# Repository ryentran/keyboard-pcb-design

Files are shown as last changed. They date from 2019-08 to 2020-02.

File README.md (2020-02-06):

# Keyboard PCB Design
This is a keyboard design for a 3x3 macropad created using KiCAD, Hasu's keyboard_parts [component library](https://github.com/tmk/kicad_lib_tmk) and [footprint library](https://github.com/tmk/keyboard_parts.pretty), and /u/techieee's [switch footprint library](https://github.com/egladman/keebs.pretty).

# Schematic
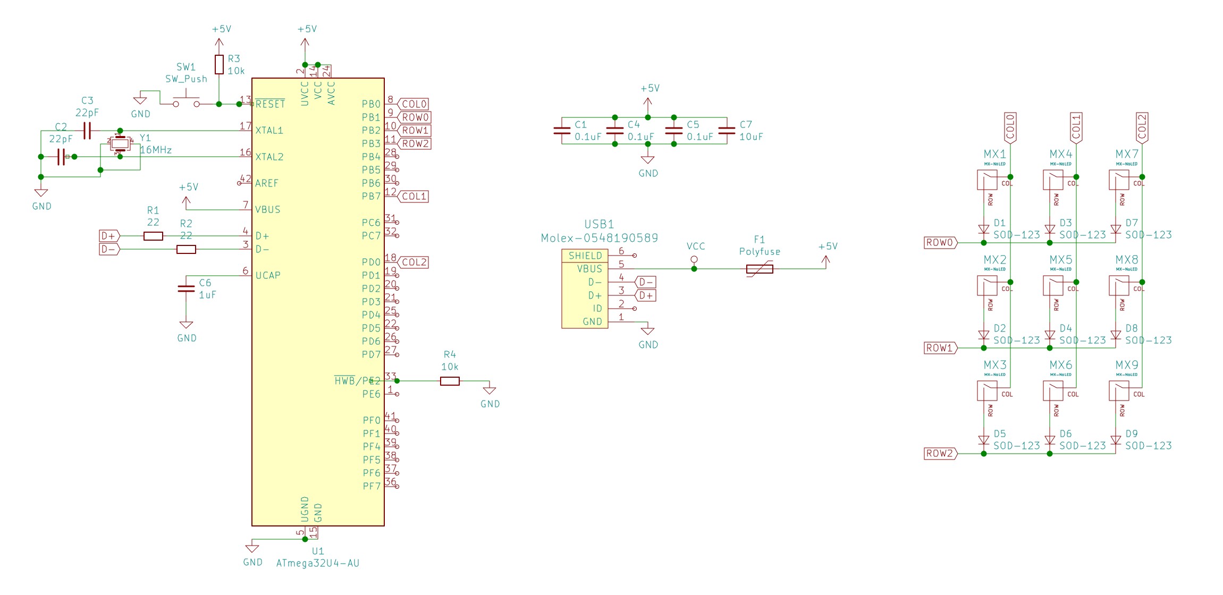
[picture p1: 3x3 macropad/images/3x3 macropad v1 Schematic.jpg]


# PCB
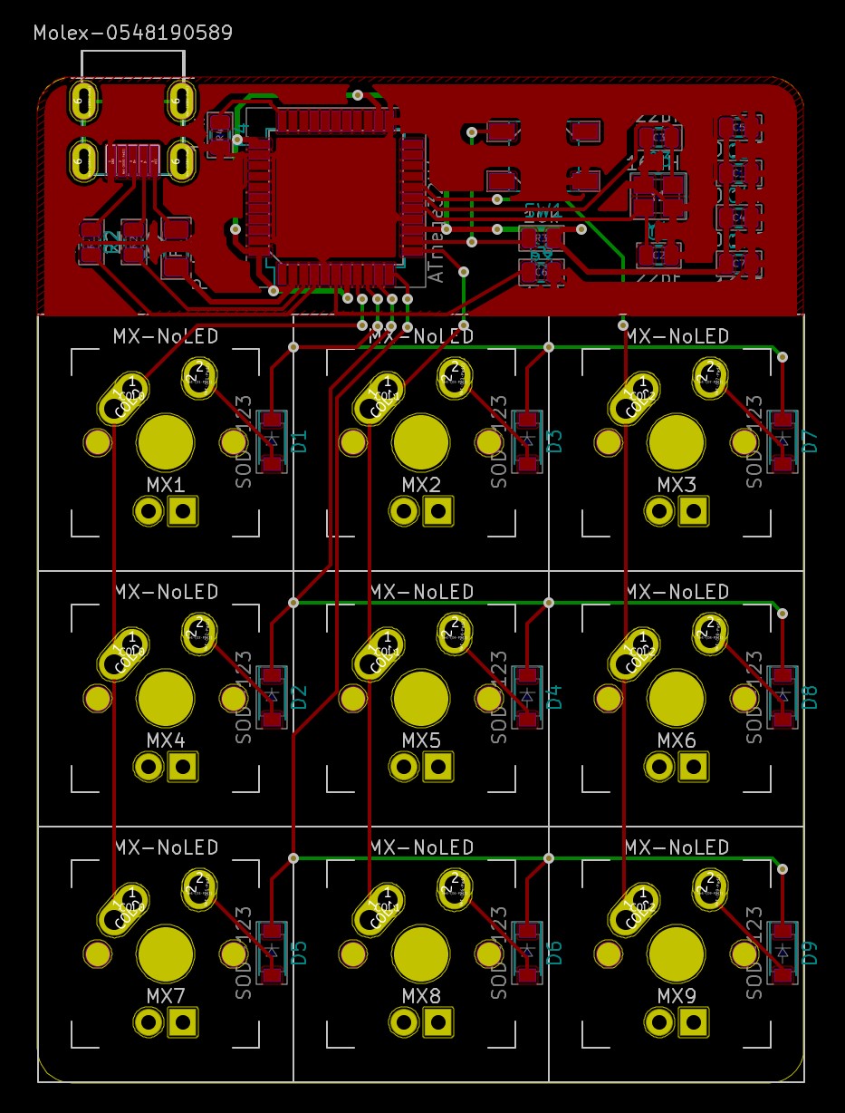
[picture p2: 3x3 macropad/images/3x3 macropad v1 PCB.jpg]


# Soldered PCB
After creating the schematic and pcb design for the macropad, the pcb was printed using prototyping services ([JLCPCB](https://jlcpcb.com/)). Once the pcb was received, SMD components were handsoldered to the board and tested for functionaility.
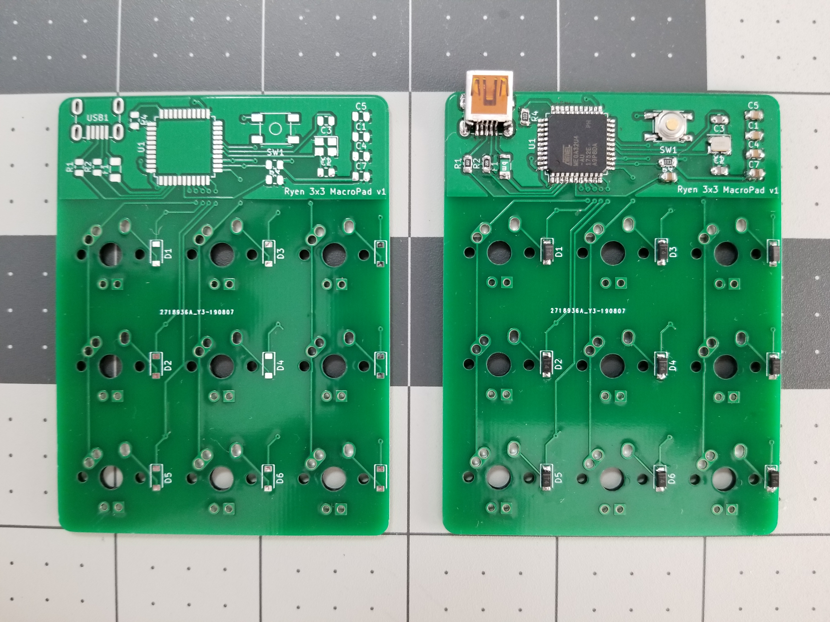
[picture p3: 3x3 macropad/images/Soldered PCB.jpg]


# Programming
The MCU used for this project is an atmega32u4 which was programmed with [QMK_firmware](https://github.com/qmk/qmk_firmware). To achieve this, the used MCU pins and key layout was defined in C header files. Once everything was setup, the hexfile was generated using a makefile and loaded onto the MCU using [QMK_toolbox](https://github.com/qmk/qmk_toolbox). To test the board, the pins across each key was shorted with a wire and the programmed key was executed.

# Mechanical Key Switches
The switches use for this macropad are Zealios 62g lubed with Krytox 205 Grade 0
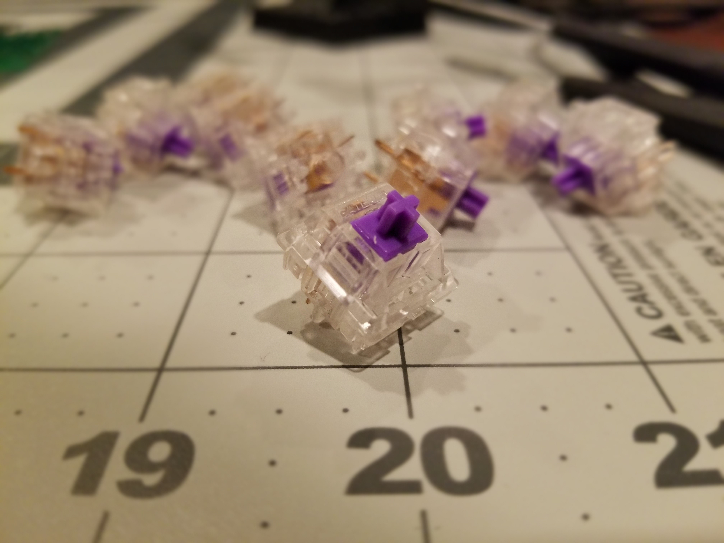
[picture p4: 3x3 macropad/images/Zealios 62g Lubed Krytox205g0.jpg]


# Finished Product
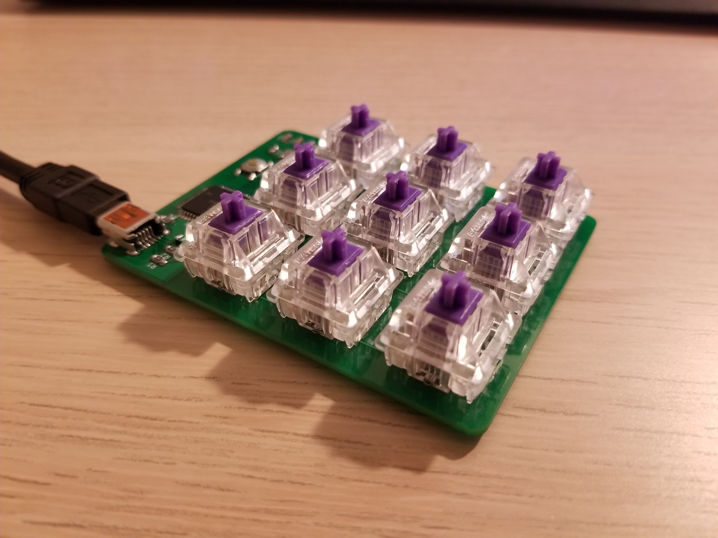
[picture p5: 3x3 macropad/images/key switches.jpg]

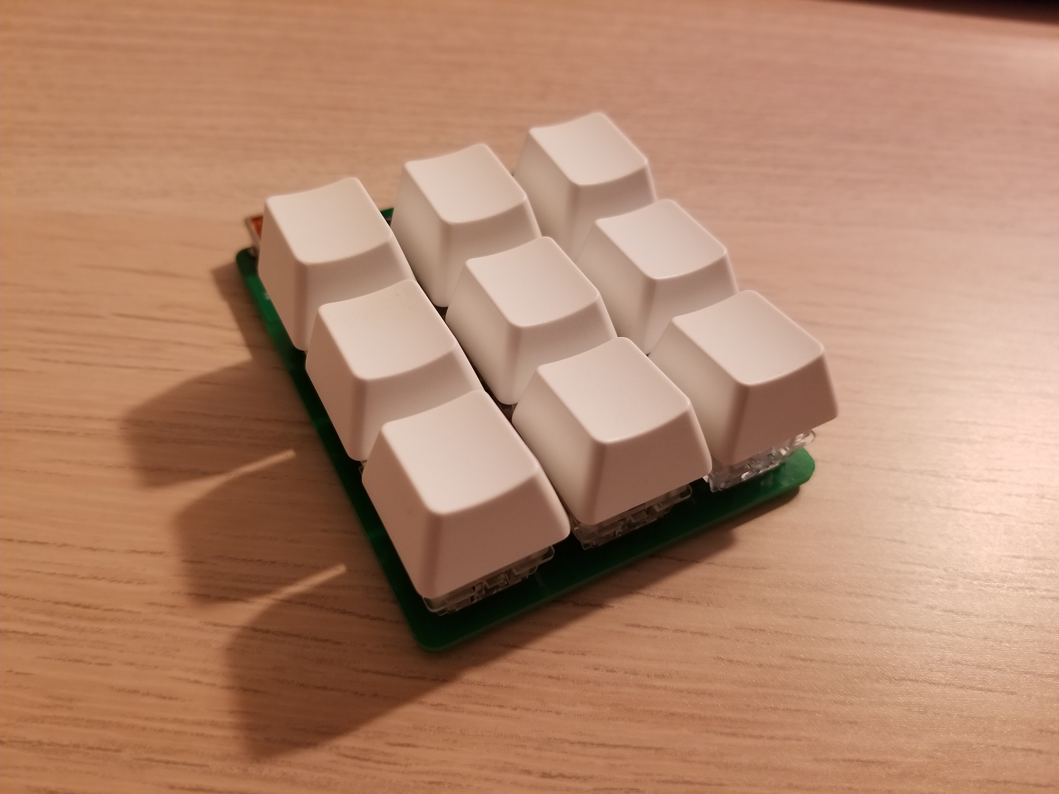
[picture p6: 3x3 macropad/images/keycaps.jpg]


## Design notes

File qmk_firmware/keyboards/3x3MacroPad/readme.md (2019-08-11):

# 3x3MacroPad

3x3MacroPad

A short description of the keyboard/project

Keyboard Maintainer: [Ryan](https://github.com/yourusername)  
Hardware Supported: The PCBs, controllers supported  
Hardware Availability: links to where you can find this hardware

Make example for this keyboard (after setting up your build environment):

    make 3x3MacroPad:default

See the [build environment setup](https://docs.qmk.fm/#/getting_started_build_tools) and the [make instructions](https://docs.qmk.fm/#/getting_started_make_guide) for more information. Brand new to QMK? Start with our [Complete Newbs Guide](https://docs.qmk.fm/#/newbs).

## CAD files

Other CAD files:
Alice/alice_plate_rev_C.DWG
Alice/alice_case_acrylic.DWG
Alice/alice_PCB_layout.DWG

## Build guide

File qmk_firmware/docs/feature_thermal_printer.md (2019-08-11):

# Thermal Printer

<!-- FIXME: Describe thermal printers support here. -->

## Thermal Printer Keycodes

|Key |Description |
|---|---|
|`PRINT_ON` |Start printing everything the user types|
|`PRINT_OFF`|Stop printing everything the user types |

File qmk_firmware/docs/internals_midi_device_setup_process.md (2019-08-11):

# group `midi_device_setup_process` {#group__midi__device__setup__process}

These are method that you must use to initialize and run a device.

## Summary

 Members                        | Descriptions                                
--------------------------------|---------------------------------------------
`public void `[`midi_device_init`](#group__midi__device__setup__process_1gaf29deddc94ea98a59daa0bde1aefd9d9)`(`[`MidiDevice`](#struct__midi__device)` * device)`            | Initialize a device.
`public void `[`midi_device_process`](#group__midi__device__setup__process_1gaa3d5993d0e998a1b59bbf5ab9c7b492b)`(`[`MidiDevice`](#struct__midi__device)` * device)`            | Process input data.

## Members

#### `public void `[`midi_device_init`](#group__midi__device__setup__process_1gaf29deddc94ea98a59daa0bde1aefd9d9)`(`[`MidiDevice`](#struct__midi__device)` * device)` {#group__midi__device__setup__process_1gaf29deddc94ea98a59daa0bde1aefd9d9}

Initialize a device.

You must call this before using the device in question.

#### Parameters
* `device` the device to initialize

#### `public void `[`midi_device_process`](#group__midi__device__setup__process_1gaa3d5993d0e998a1b59bbf5ab9c7b492b)`(`[`MidiDevice`](#struct__midi__device)` * device)` {#group__midi__device__setup__process_1gaa3d5993d0e998a1b59bbf5ab9c7b492b}

Process input data.

This method drives the input processing, you must call this method frequently if you expect to have your input callbacks called.

#### Parameters
* `device` the device to process

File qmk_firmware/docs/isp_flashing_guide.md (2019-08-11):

# ISP Flashing Guide

If you're having trouble flashing/erasing your board, and running into cryptic error messages like any of the following:

    libusb: warning [darwin_transfer_status] transfer error: timed out
    dfu.c:844: -ETIMEDOUT: Transfer timed out, NAK 0xffffffc4 (-60)
    atmel.c:1627: atmel_flash: flash data dfu_download failed.
    atmel.c:1629: Expected message length of 1072, got -60.
    atmel.c:1434: Error flashing the block: err -2.
    ERROR
    Memory write error, use debug for more info.
    commands.c:360: Error writing memory data. (err -4)

    dfu.c:844: -EPIPE: a) Babble detect or b) Endpoint stalled 0xffffffe0 (-32)
    Device is write protected.
    dfu.c:252: dfu_clear_status( 0x7fff4fc2ea80 )
    atmel.c:1434: Error flashing the block: err -2.
    ERROR
    Memory write error, use debug for more info.
    commands.c:360: Error writing memory data. (err -4)

You're likely going to need to ISP flash your board/device to get it working again. Luckily, this process is pretty straight-forward, provided you have any extra programmable keyboard, Pro Micro, or Teensy 2.0/Teensy 2.0++. There are also dedicated ISP flashers available for this, but most cost >$15, and it's assumed that if you are googling this error, this is the first you've heard about ISP flashing, and don't have one readily available (whereas you might have some other AVR board). __We'll be using a Teensy 2.0 or Pro Micro with Windows 10 in this guide__ - if you are comfortable doing this on another system, please consider editing this guide and contributing those instructions!   

## Software Needed

* [Teensy Loader](https://www.pjrc.com/teensy/loader.html) (if using a Teensy)
* QMK Toolbox (flash as usual - be sure to select the correct MCU) or `avrdude` via [WinAVR](http://www.ladyada.net/learn/avr/setup-win.html) (for Teensy & Pro Micro)

## Wiring

This is pretty straight-forward - we'll be connecting like-things to like-things in the following manner:

### Teensy 2.0

    Teensy B0  <-> Keyboard RESET
    Teensy B1  <-> Keyboard B1 (SCLK)
    Teensy B2  <-> Keyboard B2 (MOSI)
    Teensy B3  <-> Keyboard B3 (MISO)
    Teensy VCC <-> Keyboard VCC
    Teensy GND <-> Keyboard GND
    
### Pro Micro

    Pro Micro 10 (B6)  <-> Keyboard RESET
    Pro Micro 15 (B1)  <-> Keyboard B1 (SCLK)
    Pro Micro 16 (B2)  <-> Keyboard B2 (MOSI)
    Pro Micro 14 (B3)  <-> Keyboard B3 (MISO)
    Pro Micro VCC      <-> Keyboard VCC
    Pro Micro GND      <-> Keyboard GND

## The ISP Firmware (now pre-compiled)

The only difference between the .hex files below is which pin is connected to RESET. You can use them on other boards as well, as long as you're aware of the pins being used. If for some reason neither of these pins are available, [create an issue](https://github.com/qmk/qmk_firmware/issues/new), and we can generate one for you!

* Teensy 2.0: [`util/teensy_2.0_ISP_B0.hex`](https://github.com/qmk/qmk_firmware/blob/master/util/teensy_2.0_ISP_B0.hex) (`B0`)
* Pro Micro: [`util/pro_micro_ISP_B6_10.hex`](https://github.com/qmk/qmk_firmware/blob/master/util/pro_micro_ISP_B6_10.hex) (`B6/10`)

**Flash your Teenys/Pro Micro with one of these and continue - you won't need the file after flashing your ISP device.**

## Just the Bootloader File

If you just want to get things back to normal, you can flash only a bootloader from [`util/` folder](https://github.com/qmk/qmk_firmware/tree/master/util), and use your normal process to flash the firmware afterwards. Be sure to flash the correct bootloader for your chip:

* [`atmega32u4`](https://github.com/qmk/qmk_firmware/blob/master/util/bootloader_atmega32u4_1_0_0.hex) - Most keyboards, Planck Rev 1-5, Preonic Rev 1-2
* [`at90usb1286`](https://github.com/qmk/qmk_firmware/blob/master/util/bootloader_at90usb128x_1_0_1.hex) - Planck Light Rev 1
* [`atmega32a`](https://github.com/qmk/qmk_firmware/blob/master/util/bootloader_atmega32a_1_0_0.hex) - jj40

If you're not sure what your board uses, look in the `rules.mk` file for the keyboard in QMK. The `MCU =` line will have the value you need. It may differ between different versions of the board.

### Advanced/Production Techniques

If you'd like to flash both the bootloader **and** the regular firmware at the same time, you need to combine the files. 

1. Open the original firmware .hex file in a text editor
2. Remove the last line (which should be `:00000001FF` - this is an EOF message)
3. Copy the entire bootloader's contents onto a new line (with no empty lines between) and paste it at the end of the original file
4. Save it as a new file by naming it `<keyboard>_<keymap>_production.hex`

It's possible to use other bootloaders here in the same way, but __you need a bootloader__, otherwise you'll have to use ISP again to write new firmware to your keyboard.

## Flashing Your Bootloader/Production File

Make sure your keyboard is unplugged from any device, and plug in your Teensy.

### QMK Toolbox

1. `AVRISP device connected` will show up in yellow
2. Select the correct bootloader/production .hex file with the `Open` dialog (spaces can't be in the path)
3. Be sure the correct `Microcontroller` option is selected
4. Hit `Flash`
5. Wait, as nothing will output for a while, especially with production files

If the verification and fuse checks are ok, you're done! Your board may restart automatically, otherwise, unplug your Teensy and plug in your keyboard - you can leave your Teensy wired to your keyboard while testing things, but it's recommended that you desolder it/remove the wiring once you're sure everything works.

### Command Line

Open `cmd` and navigate to your where your modified .hex file is. We'll pretend this file is called `main.hex`, and that your Teensy 2.0 is on the `COM3` port - if you're unsure, you can open your Device Manager, and look for `Ports > USB Serial Device`. Use that COM port here. You can confirm it's the right port with:

    avrdude -c avrisp -P COM3 -p atmega32u4

and you should get something like the following output:

    avrdude: AVR device initialized and ready to accept instructions

    Reading | ################################################## | 100% 0.02s

    avrdude: Device signature = 0x1e9587

    avrdude: safemode: Fuses OK

    avrdude done.  Thank you.

Since our keyboard uses an `atmega32u4` (common), that is the chip we'll specify. This is the full command:

    avrdude -c avrisp -P COM3 -p atmega32u4 -U flash:w:main.hex:i

If your board uses an `atmega32a` (e.g. on a jj40), the command is this (the extra code at the end sets the fuses correctly):

	avrdude -c avrisp -P COM3 -p atmega32 -U flash:w:main.hex:i -U hfuse:w:0xD0:m -U lfuse:w:0x0F:m

You should see a couple of progress bars, then you should see:

    avrdude: verifying ...
    avrdude: 32768 bytes of flash verified

    avrdude: safemode: Fuses OK

    avrdude done.  Thank you.

Which means everything should be ok! Your board may restart automatically, otherwise, unplug your Teensy and plug in your keyboard - you can leave your Teensy wired to your keyboard while testing things, but it's recommended that you desolder it/remove the wiring once you're sure everything works.

If you have any questions/problems, feel free to [open an issue](https://github.com/qmk/qmk_firmware/issues/new)!

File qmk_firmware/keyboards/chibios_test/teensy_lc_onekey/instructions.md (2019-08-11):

# Teensy LC, 3.0, 3.1, 3.2 support

These ARM Teensies are now supported through [ChibiOS](http://chibios.org).

## Installing the ARM toolchain

You'll need to install an ARM toolchain, there is now a nice documentation about the two AVR/ARM toolchain : https://docs.qmk.fm/getting_started_build_tools.html and you can just run `sudo util/install_dependencies.sh`.
This toolchain is used instead of `avr-gcc`, which is only for AVR chips. Naturally you'll also need the usual development tools (e.g. `make`), just as in the AVR setting.

You can find others way with the [gcc ARM embedded](https://launchpad.net/gcc-arm-embedded) website, or using your favourite package manager. After installing, you should be able to run `arm-none-eabi-gcc -v` in the command prompt and get sensible output.

## Installing ChibiOS

Next, you'll need ChibiOS. For Teensies, you'll need code from two repositories: [chibios-main](https://github.com/ChibiOS/ChibiOS) and [chibios-contrib](https://github.com/ChibiOS/ChibiOS).

### If you’re using git

Run `git submodule sync --recursive && git submodule update --init --recursive`. This will install ChibiOS and ChibiOS-Contrib in the `/lib/` directory.

### If you’re not using Git

If you're not using git, you can just download a [zip of chibios from here](https://github.com/ChibiOS/ChibiOS/archive/a7df9a891067621e8e1a5c2a2c0ceada82403afe.zip), unpack the zip, and rename/move the unpacked directory (named `ChibiOS-<long_hash_here>`) to `lib/chibios/chibios` (so that the file `lib/chibios/chibios/license.txt` exists). Now the same procedure with a [zip of chibios-contrib from here](https://github.com/ChibiOS/ChibiOS-Contrib/archive/e1311c4db6cd366cf760673f769e925741ac0ad3.zip): unpack and move `ChibiOS-Contrib-<long_hash_here>` to `lib/chibios/chibios-contrib`.

(If you're using git, you can just clone the two repos: [chibios](https://github.com/ChibiOS/ChibiOS) and [chibios-contrib](https://github.com/ChibiOS/ChibiOS-Contrib). However - be warned that things may be somewhat out-of-sync (updates at different rates), so you may need to hunt a bit for the right commits.)

(Why do we need chibios-contrib? Well, the main repo focuses on STM32 chips, and Freescale/NXP Kinetis chips are supported via the Contrib repository.)

This should be it. Running `make` in `keyboard/teensy_lc_onekey` should create a working firmware in `build/`, called `ch.hex`.

For more notes about the ChibiOS backend in TMK, see `tmk_core/protocol/chibios/README.md`.

## About this onekey example

It's set up for Teensy LC. To use 3.x, you'll need to edit the `Makefile` (and comment out one line in `mcuconf.h`). A sample makefile for Teensy 3.0 is provided as `Makefile.3.0`, can be used without renaming with `make -f Makefile.3.0`. Similarly for Teensy 3.2, there's `Makefile.3.2`.

## Credits

TMK itself is written by hasu, original sources [here](https://github.com/tmk/tmk_keyboard).

The USB support for Kinetis MCUs is due to RedoX. His ChibiOS fork is also [on github](https://github.com/RedoXyde/ChibiOS); but it doesn't include Teensy LC definitions.

## Features that are not implemented yet

Currently only the more fancy suspend features are not there (power saving during suspend). The rest should work fine (reports either way are welcome).

# Matrix programming notes

The notes below explain what commands can be used to examine and set the status of Teensy pins.

## ChibiOS pin manipulation basics

### Pins

Each pin sits on a "port", each of which comprises at most 32 individual pins.
So for instance "PTC5" from Kinetis manual/datasheet refers to port C (or GPIOA), pin 5. Most functions dealing with pins take 2 parameters which specify the pin -- the first being the port, the second being the pin number.

Within ChibiOS, there are definitions which simplify this a bit for the Teensies. `TEENSY_PINn_IOPORT` represents the port of the MCU's pin connected Teensy's PIN `n`, and `TEENSY_PINn` represents its MCU's pin number.

### Mode

A MCU pin can be in several modes. The basic command to set a pin mode is

        palSetPadMode(TEENSY_PINn_IOPORT, TEENSY_PINn, PAL_MODE_INPUT_PULLUP);

The last parameter is the mode. For keyboards, the usual ones that are used are `PAL_MODE_INPUT_PULLUP` (input with a pullup), `PAL_MODE_INPUT_PULLDOWN` (input with a pulldown), `PAL_MODE_INPUT` (input floating, a.k.a. Hi-Z), `PAL_MODE_OUTPUT_PUSHPULL` (output in the Arduino sense -- can be then set HIGH or LOW).

### Setting

Pins are set HIGH (after they've been put into `OUTPUT_PUSHPULL` mode) by

        palSetPad(TEENSY_PINn_IOPORT, TEENSY_PINn);

or set LOW by

        palClearPad(TEENSY_PINn_IOPORT, TEENSY_PINn);

Toggling can be done with

        palTogglePad(TEENSY_PINn_IOPORT, TEENSY_PINn);

Alternatively, you can use

        palWritePad(TEENSY_PINn_IOPORT, TEENSY_PINn, bit);

where `bit` is either `PAL_LOW` or `PAL_HIGH` (i.e. `0` or `1`).

### Reading

Reading pin status is done with

        palReadPad(TEENSY_PINn_IOPORT, TEENSY_PINn);

The function returns either `PAL_HIGH` (actually `1`) or `PAL_LOW` (actually `0`).

### Further docs

All the commands that are available for pin manipulation through ChibiOS HAL are documented in [ChibiOS PAL driver docs](http://chibios.sourceforge.net/docs3/hal/group___p_a_l.html).

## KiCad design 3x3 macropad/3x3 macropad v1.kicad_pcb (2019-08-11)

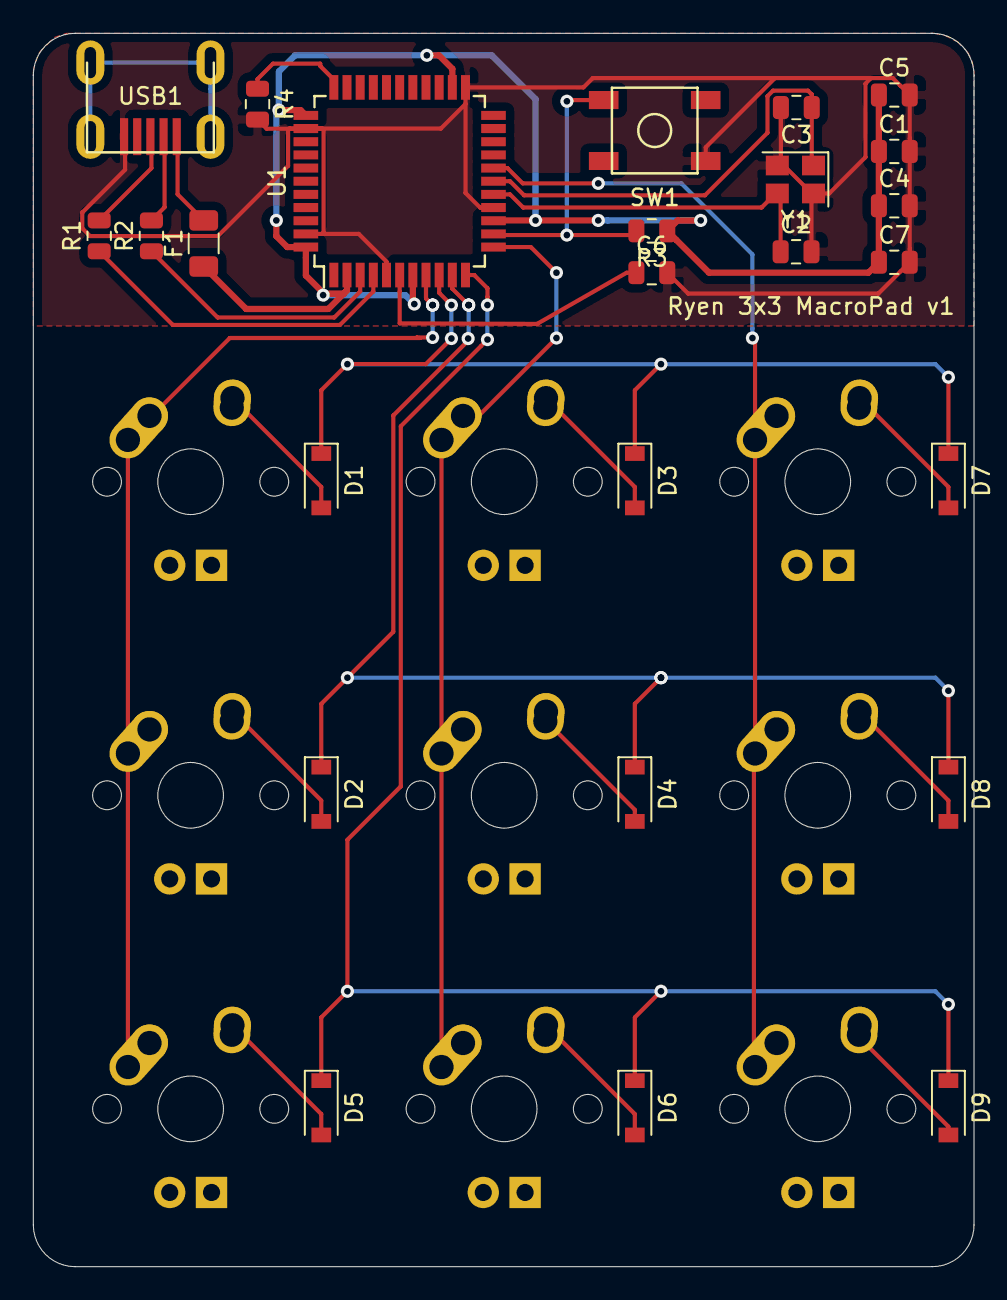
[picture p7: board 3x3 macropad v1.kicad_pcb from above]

Board: 2 copper layers, 57.2 x 74.9 mm, 34 parts (0 on the bottom side), 27 nets.

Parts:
C1, C4, C5: 0.1uF; C_0805_2012Metric
C2, C3: 22pF; C_0805_2012Metric
C6: 1uF; C_0805_2012Metric
C7: 10uF; C_0805_2012Metric
D1, D2, D3, D4, D5, D6, D7, D8, D9: SOD-123; D_SOD-123
F1: Polyfuse; Fuse_1206_3216Metric
MX1, MX2, MX3, MX4, MX5, MX6, MX7, MX8, MX9: MX-NoLED; MX-1U
R1, R2: 22; R_0805_2012Metric
R3, R4: 10k; R_0805_2012Metric
SW1: SW_Push; SKQG-1155865
U1: ATmega32U4-AU; TQFP-44_10x10mm_P0.8mm
USB1: Molex-0548190589
Y1: 16MHz; Crystal_SMD_3225-4Pin_3.2x2.5mm

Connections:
+5V: C1.1, C4.1, C5.1, C7.1, F1.1, R3.1, U1.2, U1.7, U1.14, U1.24, U1.34, U1.44
COL0: MX1.1, MX4.1, MX7.1, U1.8
COL1: MX2.1, MX5.1, MX8.1, U1.12
COL2: MX3.1, MX6.1, MX9.1, U1.18
D+: R1.2, USB1.3
D-: R2.2, USB1.4
GND: C1.2, C2.2, C3.2, C4.2, C5.2, C6.2, C7.2, R4.2, SW1.1, U1.5, U1.15, U1.23, U1.35, U1.43, USB1.1, Y1.2, Y1.4
unnamed: C2.1, U1.16, Y1.3
unnamed: C3.1, U1.17, Y1.1
unnamed: C6.1, U1.6
unnamed: D1.2, MX1.2
unnamed: D2.2, MX4.2
unnamed: D3.2, MX2.2
unnamed: D4.2, MX5.2
unnamed: D5.2, MX7.2
unnamed: D6.2, MX8.2
unnamed: D7.2, MX3.2
unnamed: D8.2, MX6.2
unnamed: D9.2, MX9.2
unnamed: R1.1, U1.4
unnamed: R2.1, U1.3
unnamed: R3.2, SW1.2, U1.13
unnamed: R4.1, U1.33
ROW0: D1.1, D3.1, D7.1, U1.9
ROW1: D2.1, D4.1, D8.1, U1.10
ROW2: D5.1, D6.1, D9.1, U1.11
VCC: F1.2, USB1.5

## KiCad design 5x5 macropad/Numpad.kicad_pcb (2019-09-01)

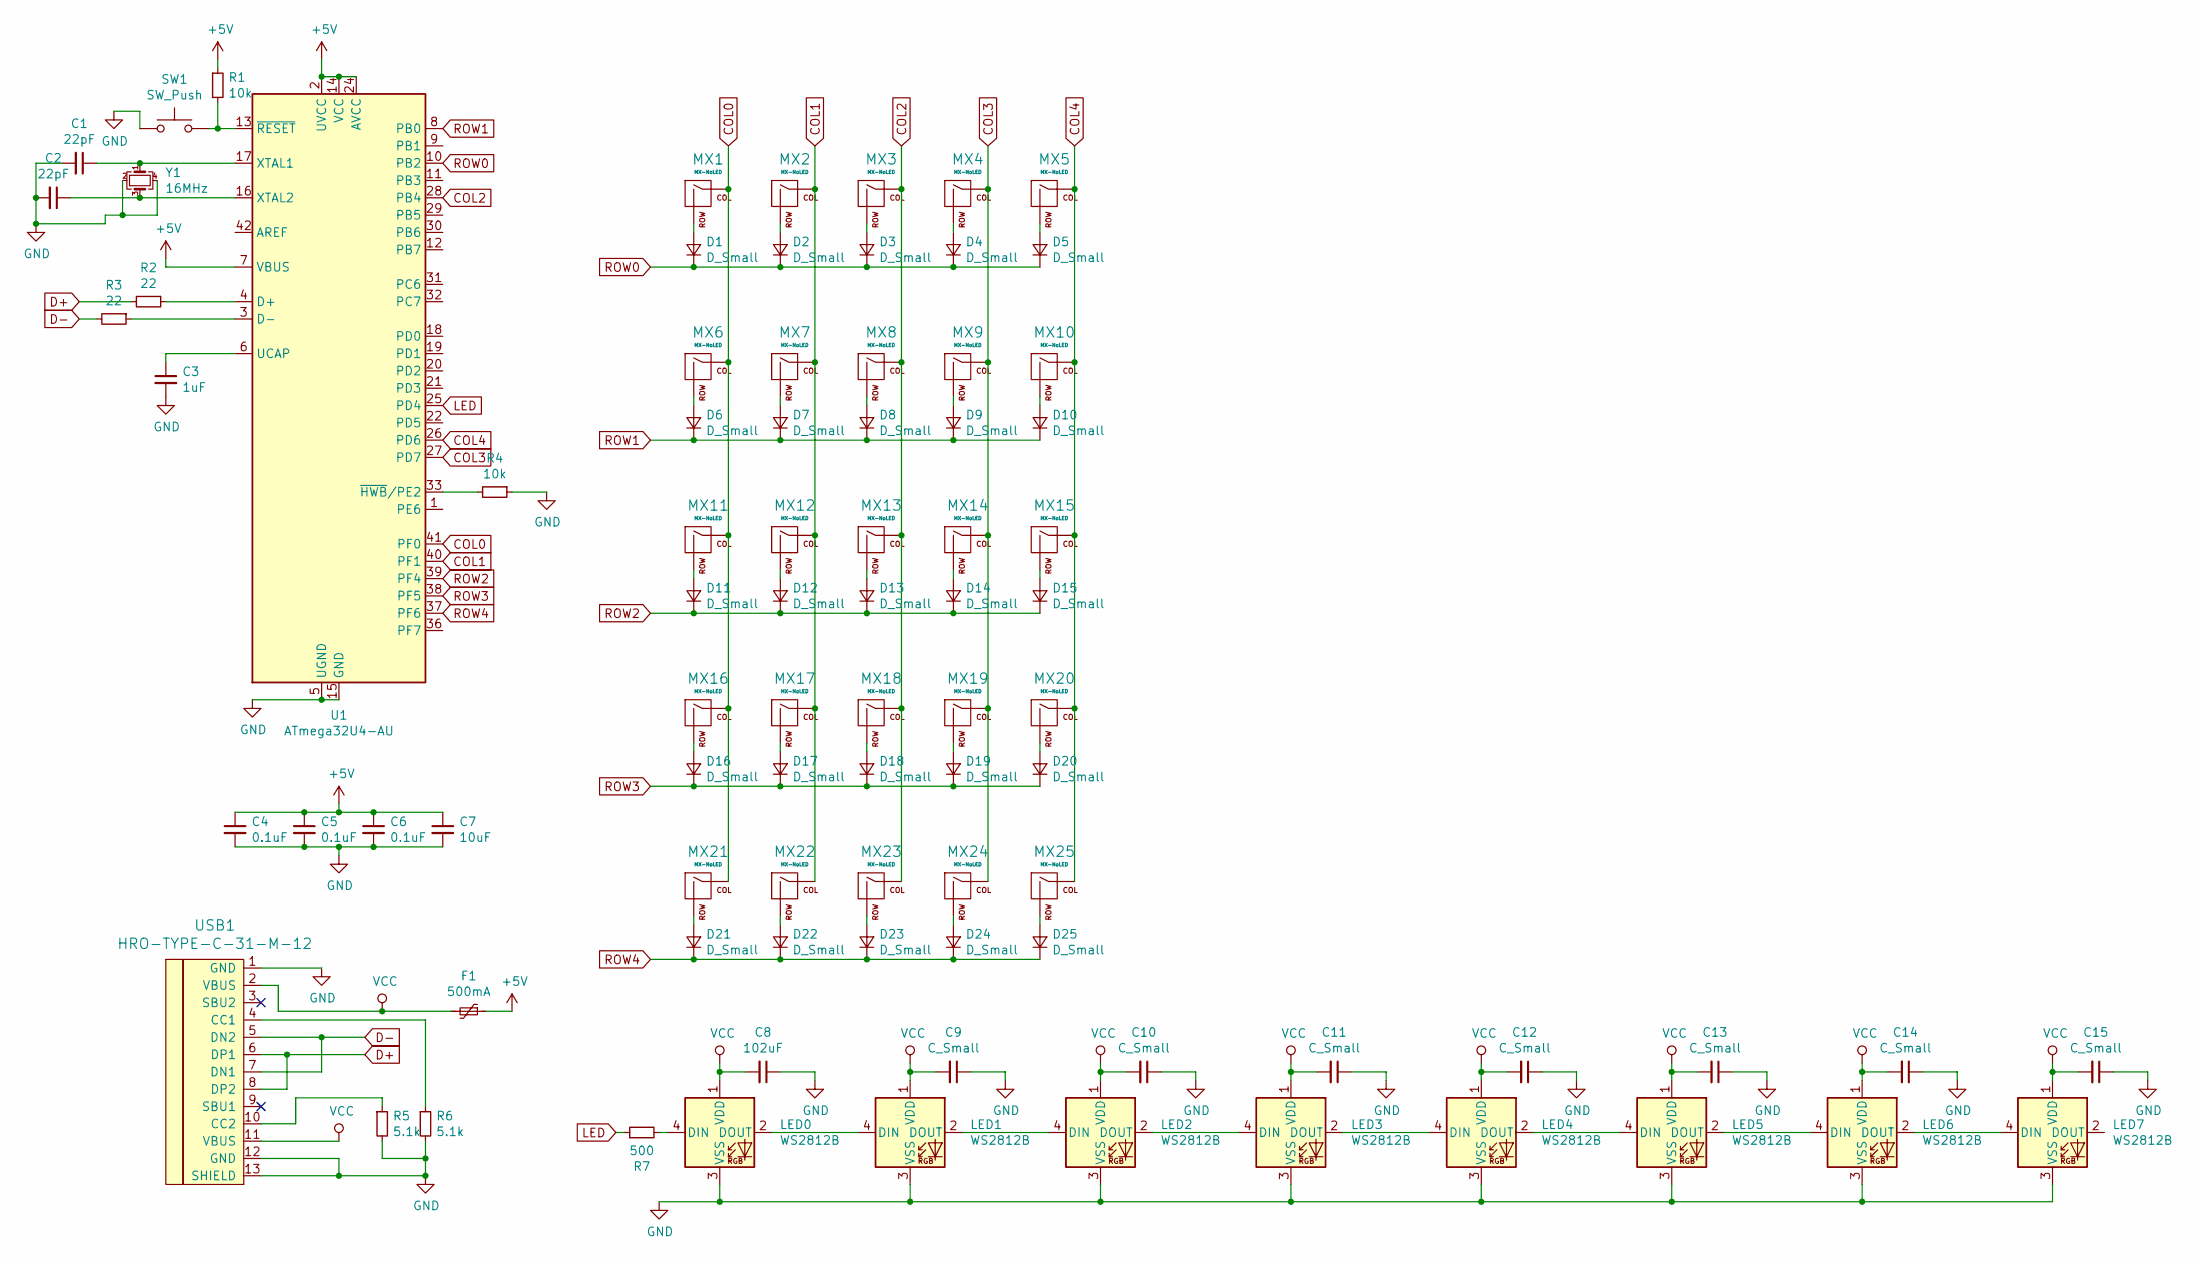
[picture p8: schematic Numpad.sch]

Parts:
C1, C2: 22pF; C_0805_2012Metric_Pad1.15x1.40mm_HandSolder
C3: 1uF; C_0805_2012Metric_Pad1.15x1.40mm_HandSolder
C4, C5, C6: 0.1uF; C_0805_2012Metric_Pad1.15x1.40mm_HandSolder
C7: 10uF; C_0805_2012Metric_Pad1.15x1.40mm_HandSolder
C8: 102uF; C_0805_2012Metric_Pad1.15x1.40mm_HandSolder
C9, C10, C11, C12, C13, C14, C15: C_Small; C_0805_2012Metric_Pad1.15x1.40mm_HandSolder
D1, D2, D3, D4, D5, D6, D7, D8, D9, D10, D11, D12, D13, D14, D15, D16, D17, D18, D19, D20, D21, D22, D23, D24, D25: D_Small; D_SOD-123
F1: 500mA; Fuse_1206_3216Metric_Pad1.42x1.75mm_HandSolder
LED0, LED1, LED2, LED3, LED4, LED5, LED6, LED7: WS2812B; LED_WS2812B_PLCC4_5.0x5.0mm_P3.2mm
MX1, MX2, MX3, MX4, MX5, MX6, MX7, MX8, MX9, MX10, MX11, MX12, MX13, MX14, MX15, MX16, MX17, MX18, MX19, MX20, MX21, MX22, MX23, MX24, MX25: MX-NoLED; MXOnly-1U-NoLED
R1, R4: 10k; R_0805_2012Metric_Pad1.15x1.40mm_HandSolder
R2, R3: 22; R_0805_2012Metric_Pad1.15x1.40mm_HandSolder
R5, R6: 5.1k; R_0805_2012Metric_Pad1.15x1.40mm_HandSolder
R7: 500; R_0805_2012Metric_Pad1.15x1.40mm_HandSolder
SW1: SW_Push; SKQG-1155865
U1: ATmega32U4-AU; TQFP-44_10x10mm_P0.8mm
USB1: HRO-TYPE-C-31-M-12; HRO-TYPE-C-31-M-12-HandSoldering
Y1: 16MHz; Crystal_SMD_3225-4Pin_3.2x2.5mm_HandSoldering

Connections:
+5V: C4.1, C5.1, C6.1, C7.1, F1.1, R1.1, U1.2 (UVCC), U1.7 (VBUS), U1.14 (VCC), U1.24 (AVCC), U1.34 (VCC), U1.44 (AVCC)
COL0: MX1.1 (COL), MX6.1 (COL), MX11.1 (COL), MX16.1 (COL), MX21.1 (COL), U1.41 (PF0)
COL1: MX2.1 (COL), MX7.1 (COL), MX12.1 (COL), MX17.1 (COL), MX22.1 (COL), U1.40 (PF1)
COL2: MX3.1 (COL), MX8.1 (COL), MX13.1 (COL), MX18.1 (COL), MX23.1 (COL), U1.28 (PB4)
COL3: MX4.1 (COL), MX9.1 (COL), MX14.1 (COL), MX19.1 (COL), MX24.1 (COL), U1.27 (PD7)
COL4: MX5.1 (COL), MX10.1 (COL), MX15.1 (COL), MX20.1 (COL), MX25.1 (COL), U1.26 (PD6)
D+: R2.2, USB1.6 (DP1), USB1.8 (DP2)
D-: R3.2, USB1.5 (DN2), USB1.7 (DN1)
GND: C1.2, C2.2, C3.2, C4.2, C5.2, C6.2, C7.2, C8.1, C9.1, C10.1, C11.1, C12.1, C13.1, C14.1, C15.1, LED0.3 (VSS), LED1.3 (VSS), LED2.3 (VSS), LED3.3 (VSS), LED4.3 (VSS), LED5.3 (VSS), LED6.3 (VSS), LED7.3 (VSS), R4.1, R5.2, R6.2, SW1.1, U1.5 (UGND), U1.15 (GND), U1.23 (GND), U1.35 (GND), U1.43 (GND), USB1.1 (GND), USB1.12 (GND), USB1.13 (SHIELD), Y1.2, Y1.4
LED: R7.1, U1.25 (PD4)
unnamed: C1.1, U1.17 (XTAL1), Y1.1
unnamed: C2.1, U1.16 (XTAL2), Y1.3
unnamed: C3.1, U1.6 (UCAP)
unnamed: D1.2 (A), MX1.2 (ROW)
unnamed: D2.2 (A), MX2.2 (ROW)
unnamed: D3.2 (A), MX3.2 (ROW)
unnamed: D4.2 (A), MX4.2 (ROW)
unnamed: D5.2 (A), MX5.2 (ROW)
unnamed: D6.2 (A), MX6.2 (ROW)
unnamed: D7.2 (A), MX7.2 (ROW)
unnamed: D8.2 (A), MX8.2 (ROW)
unnamed: D9.2 (A), MX9.2 (ROW)
unnamed: D10.2 (A), MX10.2 (ROW)
unnamed: D11.2 (A), MX11.2 (ROW)
unnamed: D12.2 (A), MX12.2 (ROW)
unnamed: D13.2 (A), MX13.2 (ROW)
unnamed: D14.2 (A), MX14.2 (ROW)
unnamed: D15.2 (A), MX15.2 (ROW)
unnamed: D16.2 (A), MX16.2 (ROW)
unnamed: D17.2 (A), MX17.2 (ROW)
unnamed: D18.2 (A), MX18.2 (ROW)
unnamed: D19.2 (A), MX19.2 (ROW)
unnamed: D20.2 (A), MX20.2 (ROW)
unnamed: D21.2 (A), MX21.2 (ROW)
unnamed: D22.2 (A), MX22.2 (ROW)
unnamed: D23.2 (A), MX23.2 (ROW)
unnamed: D24.2 (A), MX24.2 (ROW)
unnamed: D25.2 (A), MX25.2 (ROW)
unnamed: LED0.2 (DOUT), LED1.4 (DIN)
unnamed: LED0.4 (DIN), R7.2
unnamed: LED1.2 (DOUT), LED2.4 (DIN)
unnamed: LED2.2 (DOUT), LED3.4 (DIN)
unnamed: LED3.2 (DOUT), LED4.4 (DIN)
unnamed: LED4.2 (DOUT), LED5.4 (DIN)
unnamed: LED5.2 (DOUT), LED6.4 (DIN)
unnamed: LED6.2 (DOUT), LED7.4 (DIN)
unnamed: R1.2, SW1.2, U1.13 (~RESET)
unnamed: R2.1, U1.4 (D+)
unnamed: R3.1, U1.3 (D-)
unnamed: R4.2, U1.33 (~HWB~/PE2)
unnamed: R5.1, USB1.10 (CC2)
unnamed: R6.1, USB1.4 (CC1)
ROW0: D1.1 (K), D2.1 (K), D3.1 (K), D4.1 (K), D5.1 (K), U1.10 (PB2)
ROW1: D6.1 (K), D7.1 (K), D8.1 (K), D9.1 (K), D10.1 (K), U1.8 (PB0)
ROW2: D11.1 (K), D12.1 (K), D13.1 (K), D14.1 (K), D15.1 (K), U1.39 (PF4)
ROW3: D16.1 (K), D17.1 (K), D18.1 (K), D19.1 (K), D20.1 (K), U1.38 (PF5)
ROW4: D21.1 (K), D22.1 (K), D23.1 (K), D24.1 (K), D25.1 (K), U1.37 (PF6)
VCC: C8.2, C9.2, C10.2, C11.2, C12.2, C13.2, C14.2, C15.2, F1.2, LED0.1 (VDD), LED1.1 (VDD), LED2.1 (VDD), LED3.1 (VDD), LED4.1 (VDD), LED5.1 (VDD), LED6.1 (VDD), LED7.1 (VDD), USB1.2 (VBUS), USB1.11 (VBUS)

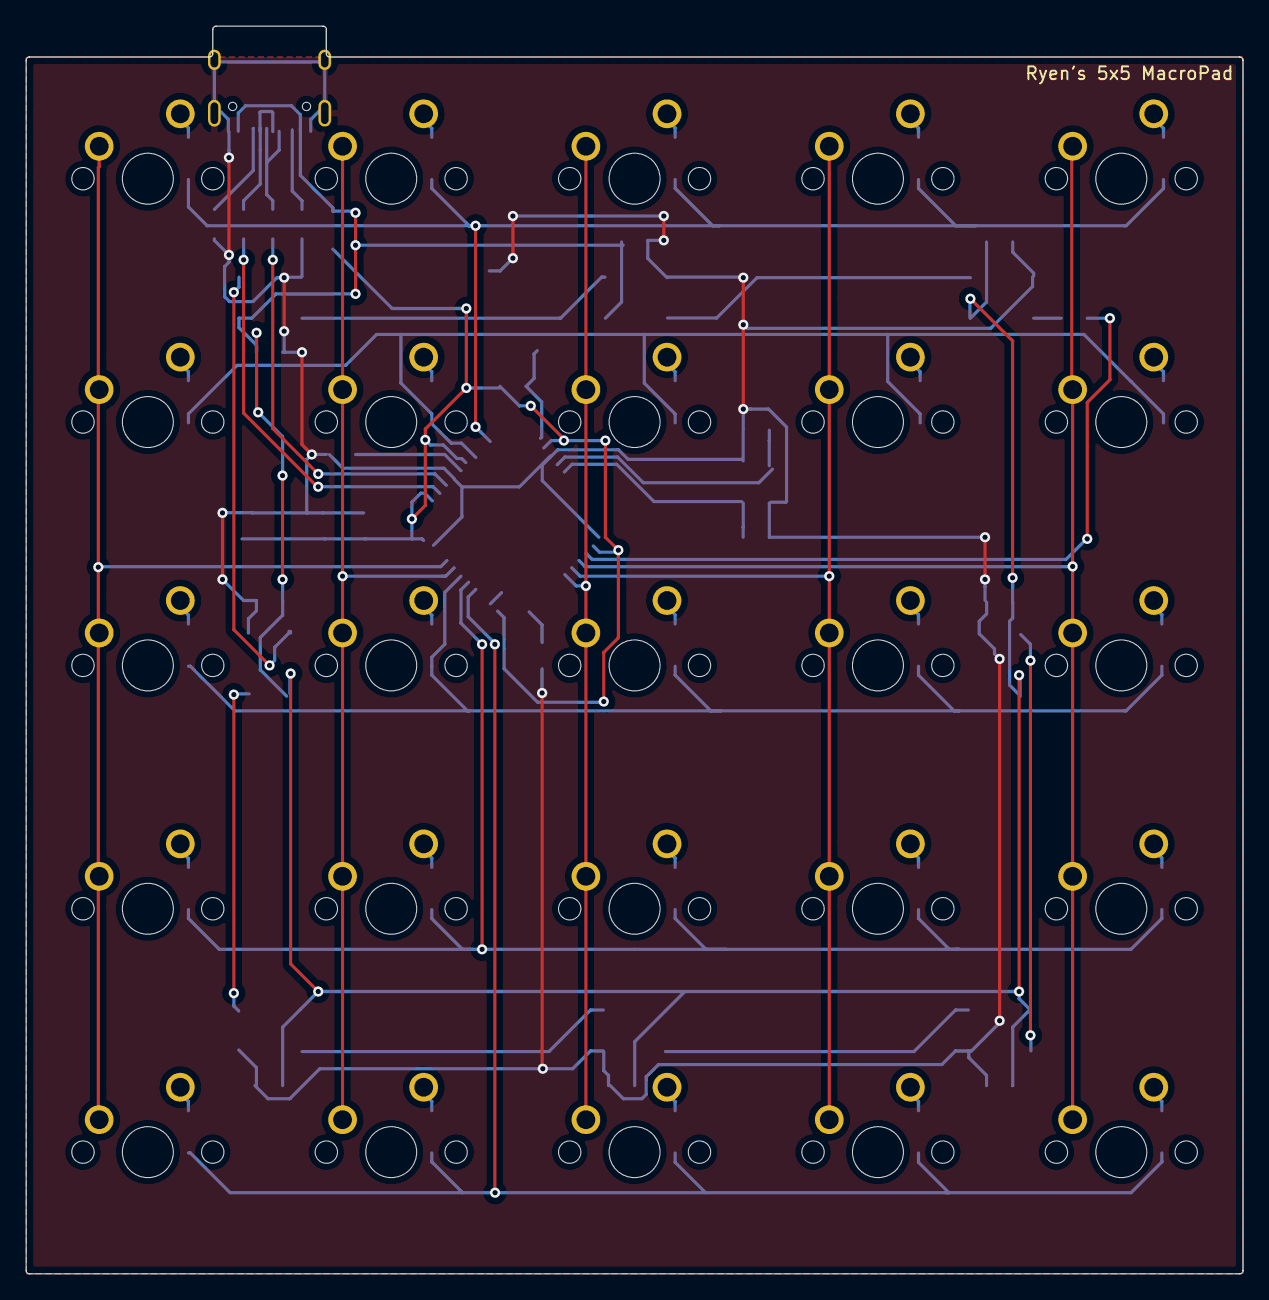
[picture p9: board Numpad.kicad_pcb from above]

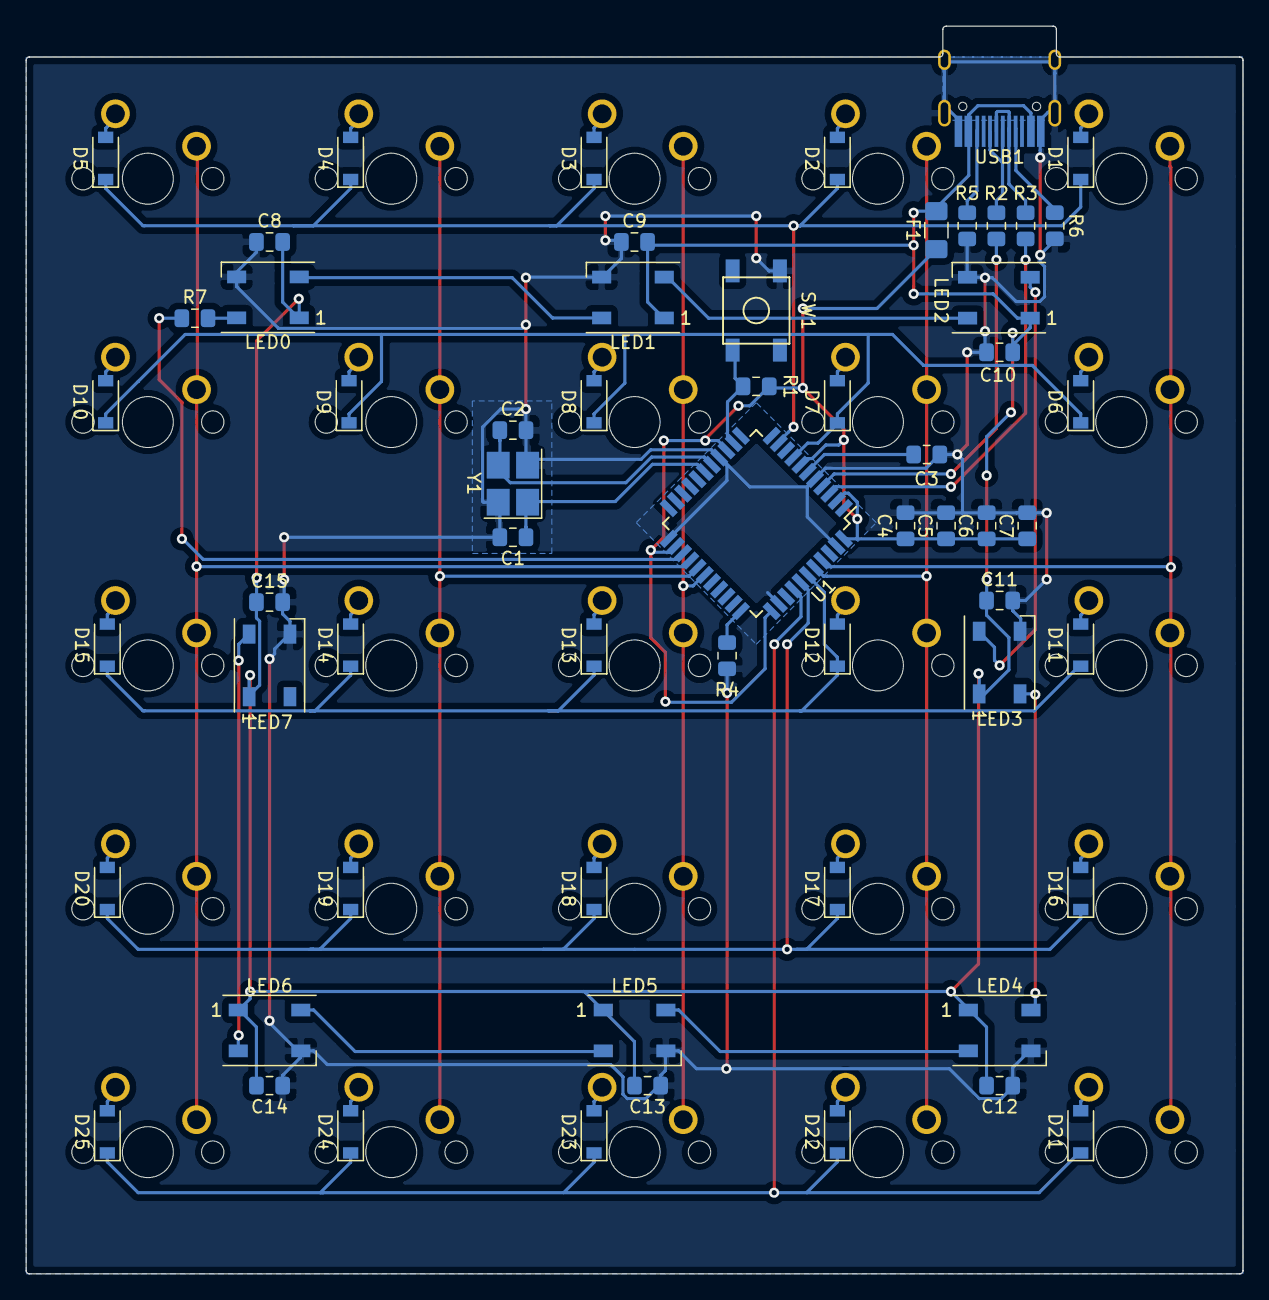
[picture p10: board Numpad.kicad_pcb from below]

Board: 2 copper layers, 95.2 x 97.7 mm, 85 parts (60 on the bottom side), 58 nets.

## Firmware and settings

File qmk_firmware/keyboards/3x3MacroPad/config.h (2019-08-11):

/*
Copyright 2019 Ryan

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
You should have received a copy of the GNU General Public License
along with this program.  If not, see <http://www.gnu.org/licenses/>.
*/

#pragma once

#include "config_common.h"

/* USB Device descriptor parameter */
#define VENDOR_ID       0xFEED
#define PRODUCT_ID      0x0000
#define DEVICE_VER      0x0001
#define MANUFACTURER    Ryan
#define PRODUCT         3x3MacroPad
#define DESCRIPTION     A custom keyboard

/* key matrix size */
#define MATRIX_ROWS 3 
#define MATRIX_COLS 3

/*
 * Keyboard Matrix Assignments
 *
 * Change this to how you wired your keyboard
 * COLS: AVR pins used for columns, left to right
 * ROWS: AVR pins used for rows, top to bottom
 * DIODE_DIRECTION: COL2ROW = COL = Anode (+), ROW = Cathode (-, marked on diode)
 *                  ROW2COL = ROW = Anode (+), COL = Cathode (-, marked on diode)
 *
*/
#define MATRIX_ROW_PINS { B1, B2, B3 }
#define MATRIX_COL_PINS { B0, B7, D0 }
#define UNUSED_PINS

/* COL2ROW, ROW2COL*/
#define DIODE_DIRECTION COL2ROW

/*
 * Split Keyboard specific options, make sure you have 'SPLIT_KEYBOARD = yes' in your rules.mk, and define SOFT_SERIAL_PIN.
 */
#define SOFT_SERIAL_PIN D0 // or D1, D2, D3, E6

// #define BACKLIGHT_PIN B7
// #define BACKLIGHT_BREATHING
// #define BACKLIGHT_LEVELS 3

// #define RGB_DI_PIN E2
// #ifdef RGB_DI_PIN
//   #define RGBLED_NUM 16
//   #define RGBLIGHT_HUE_STEP 8
//   #define RGBLIGHT_SAT_STEP 8
//   #define RGBLIGHT_VAL_STEP 8
//   #define RGBLIGHT_LIMIT_VAL 255 /* The maximum brightness level */
//   #define RGBLIGHT_SLEEP  /* If defined, the RGB lighting will be switched off when the host goes to sleep */
// /*== all animations enable ==*/
//   #define RGBLIGHT_ANIMATIONS
// /*== or choose animations ==*/
//   #define RGBLIGHT_EFFECT_BREATHING
//   #define RGBLIGHT_EFFECT_RAINBOW_MOOD
//   #define RGBLIGHT_EFFECT_RAINBOW_SWIRL
//   #define RGBLIGHT_EFFECT_SNAKE
//   #define RGBLIGHT_EFFECT_KNIGHT
//   #define RGBLIGHT_EFFECT_CHRISTMAS
//   #define RGBLIGHT_EFFECT_STATIC_GRADIENT
//   #define RGBLIGHT_EFFECT_RGB_TEST
//   #define RGBLIGHT_EFFECT_ALTERNATING
// /*== customize breathing effect ==*/
//   /*==== (DEFAULT) use fixed table instead of exp() and sin() ====*/
//   #define RGBLIGHT_BREATHE_TABLE_SIZE 256      // 256(default) or 128 or 64
//   /*==== use exp() and sin() ====*/
//   #define RGBLIGHT_EFFECT_BREATHE_CENTER 1.85  // 1 to 2.7
//   #define RGBLIGHT_EFFECT_BREATHE_MAX    255   // 0 to 255
// #endif

/* Debounce reduces chatter (unintended double-presses) - set 0 if debouncing is not needed */
#define DEBOUNCE 5

/* define if matrix has ghost (lacks anti-ghosting diodes) */
//#define MATRIX_HAS_GHOST

/* Mechanical locking support. Use KC_LCAP, KC_LNUM or KC_LSCR instead in keymap */
#define LOCKING_SUPPORT_ENABLE
/* Locking resynchronize hack */
#define LOCKING_RESYNC_ENABLE

/* If defined, GRAVE_ESC will always act as ESC when CTRL is held.
 * This is userful for the Windows task manager shortcut (ctrl+shift+esc).
 */
// #define GRAVE_ESC_CTRL_OVERRIDE

/*
 * Force NKRO
 *
 * Force NKRO (nKey Rollover) to be enabled by default, regardless of the saved
 * state in the bootmagic EEPROM settings. (Note that NKRO must be enabled in the
 * makefile for this to work.)
 *
 * If forced on, NKRO can be disabled via magic key (default = LShift+RShift+N)
 * until the next keyboard reset.
 *
 * NKRO may prevent your keystrokes from being detected in the BIOS, but it is
 * fully operational during normal computer usage.
 *
 * For a less heavy-handed approach, enable NKRO via magic key (LShift+RShift+N)
 * or via bootmagic (hold SPACE+N while plugging in the keyboard). Once set by
 * bootmagic, NKRO mode will always be enabled until it is toggled again during a
 * power-up.
 *
 */
//#define FORCE_NKRO

/*
 * Magic Key Options
 *
 * Magic keys are hotkey commands that allow control over firmware functions of
 * the keyboard. They are best used in combination with the HID Listen program,
 * found here: https://www.pjrc.com/teensy/hid_listen.html
 *
 * The options below allow the magic key functionality to be changed. This is
 * useful if your keyboard/keypad is missing keys and you want magic key support.
 *
 */

/* key combination for magic key command */
/* defined by default; to change, uncomment and set to the combination you want */
// #define IS_COMMAND() (get_mods() == MOD_MASK_SHIFT)

/* control how magic key switches layers */
//#define MAGIC_KEY_SWITCH_LAYER_WITH_FKEYS  true
//#define MAGIC_KEY_SWITCH_LAYER_WITH_NKEYS  true
//#define MAGIC_KEY_SWITCH_LAYER_WITH_CUSTOM false
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

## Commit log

2019-08-05 added libraries to project
    [first-keyboard.kicad_pcb, first-keyboard.sch]
2019-08-06 3x3 macropad v1
    [first-keyboard-B_Cu.gbl, first-keyboard-B_Mask.gbs, first-keyboard-B_Paste.gbp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]
2019-08-06 renamed project
    [first-keyboard-B_Cu.gbl, first-keyboard-B_Mask.gbs, first-keyboard-B_Paste.gbp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]
2019-08-11 Fixed schematic, added QMK Firmware
    [3x3 macropad v1.kicad_pcb, 3x3 macropad v1.sch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]
2019-08-11 Added images
    [3x3 macropad v1.sch]
2019-08-11 added qmk_firmware
    [kinesis.sch, matrix.csv]
2019-08-14 added usb c library, eemr tkl project
    [EEMR TKL Keyboard.kicad_pcb, EEMR TKL Keyboard.sch]
2019-08-14 completed schematic for tkl
    [EEMR TKL Keyboard.sch]
2019-08-14 removed empty directory
    [EEMR TKL Keyboard.kicad_pcb, EEMR TKL Keyboard.sch]
2019-08-21 new projects
    [EEMR TKL Keyboard.sch]
2019-08-28 numpad/5x5 macropad project
    [3x3 macropad v1.sch, Numpad.kicad_pcb, Numpad.sch]
2019-09-01 finished pcb routing
    [Numpad.kicad_pcb, Numpad.sch]
2020-02-06 modified directories
    [3x3 macropad v1.kicad_pcb, 3x3 macropad v1.sch, EEMR TKL Keyboard.kicad_pcb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]
2020-05-06 Alice pcb, created schematic symbols
    [Alice.PrjPcb, Schlib1.SchLib, Sheet1.SchDoc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]

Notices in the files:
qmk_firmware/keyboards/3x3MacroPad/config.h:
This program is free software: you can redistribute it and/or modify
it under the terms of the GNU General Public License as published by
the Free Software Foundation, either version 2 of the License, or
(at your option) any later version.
